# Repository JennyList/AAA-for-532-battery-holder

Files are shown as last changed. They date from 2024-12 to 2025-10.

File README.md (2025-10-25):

# AAA-for-532-battery-holder

A 3D printable battery holder designed to replace an Ever Ready 532 battery with 2 AAA cells in 1960s bellows Polaroid cameras

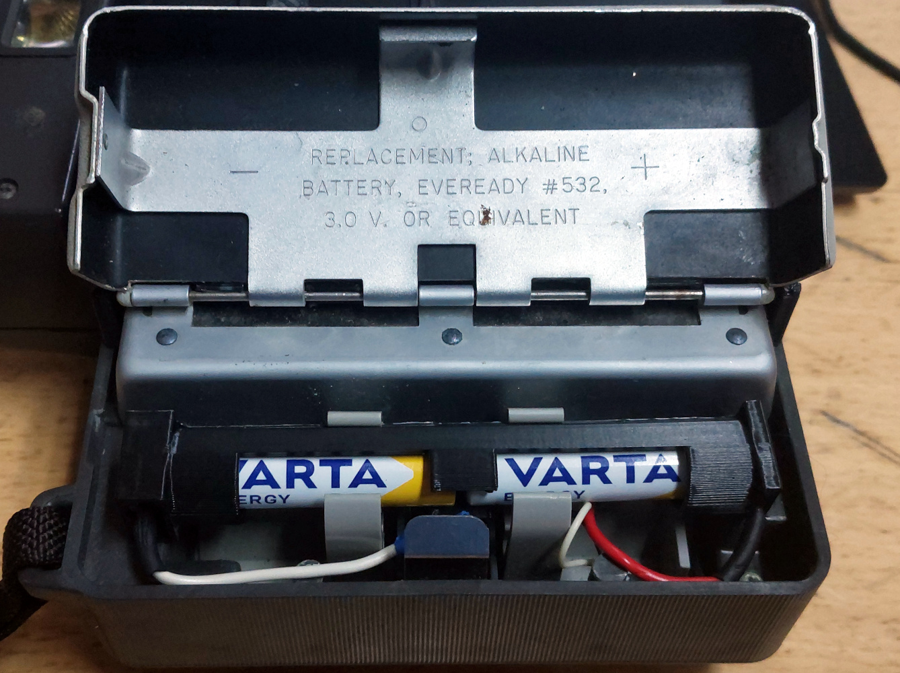
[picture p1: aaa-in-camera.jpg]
The battery holder fitted in a Polaroid 104 camera, with a pair of Varta AAA cells


## Instructions

Print the model, either from the STL file or by rendering the OpenSCAD file. I printed mine on a Prusa Mini, with a brim and with supports on the bed.

I found some spring battery terminals designed for battery boxes on AliExpress. Mine were the coiled wire type, and were designed to connect the positive of one cell to the negative of the next. I cut one into two terminals and soldered the two to a pair of wires, as shown in the image below. The spring terminals should slide into the 3D printed receptacle, the wider one being for the negative spring. You may find a set of tweezers useful here. The clip style connectors in the camera were removed, and the wires from the battery holder soldered to their wires, observing polarity. I used heat shrink sleeving for insulation on all connectors.

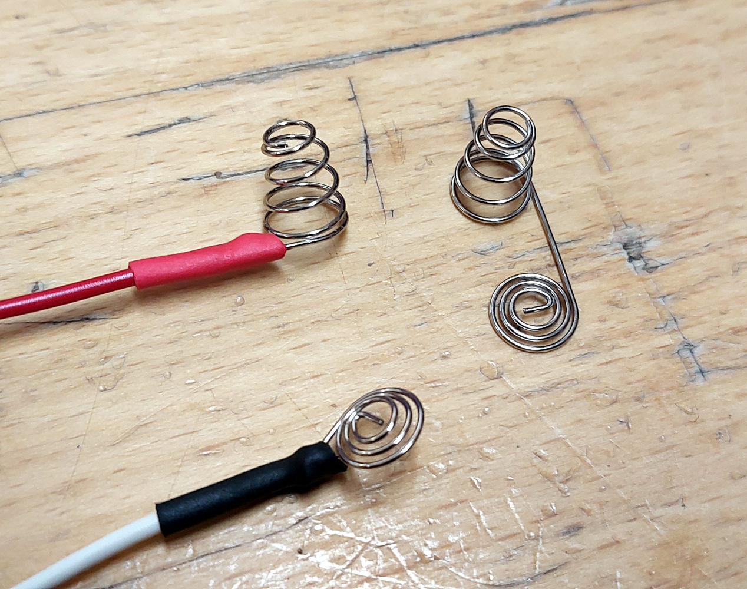
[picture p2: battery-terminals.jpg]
The battery terminals, next to one of the spring terminals I cut in half to make mine.


The resulting AAA battery holder should fit in the clip for the 532, and be short enough to fit within the battery compartment of the camera. This was tested in a Polaroid 104, and it should also work with other similar models.



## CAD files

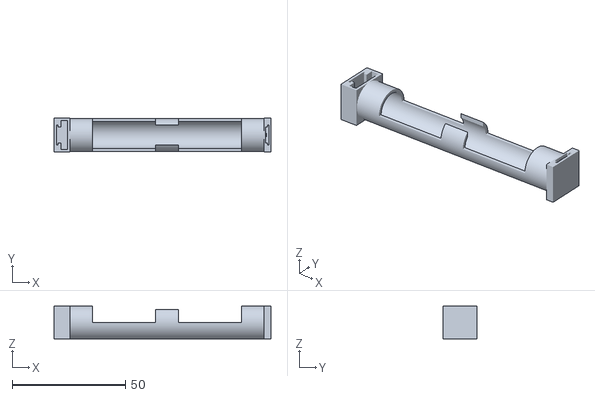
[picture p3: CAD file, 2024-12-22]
AAA-for-532-battery-holder.stl
96.0 x 15.0 x 14.5

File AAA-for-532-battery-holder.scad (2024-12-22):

/*
A 3D-printable adapter from an Ever Ready 532 to two AAA cells

(c) Jenny List 2024
CC-BY-SA 4.0

Designed for 1960s Polaroid bellows cameras which used this cell.
Tested on a Polaroid 104, other similar cameras use the same batteries.

I print this with a brim, and supports on the bed.

*/

module AAAcell(){
    cylinder(42.45,5.1,5.1);
    translate([0,0,42.45]) cylinder(1.12,1.6,1.6);
}


//translate([0,0,10]) AAAcell();
//translate([0,0,53.57]) AAAcell();
$fn=90;

rotate([0,90,0]){
    difference(){
        union(){
            translate([-7.25,-7.5,0]){
                difference(){ // -ve contact
                    cube([14.5,15,7]);
                    translate([0,1,3]) cube([13,13,3]);
                    translate([0,4,1.75]) cube([13,7,2.25]);
                    translate([0,3,1]) cube([13,9,0.75]);
                }
            }
            translate([-7.25,-7.5,93]){
                difference(){ // +ve contact
                    cube([14.5,15,3]);
                    translate([0,4,0.6]) cube([13,7,0.75]);
                    translate([0,3,1.35]) cube([13,9,0.75]);
                }
            }
            translate([0,0,7]) {
                difference(){//battery tube for 2 AAA cells
                    cylinder(86,7.25,7.25);
                    translate([-10,-4.5,10]) cube([10,9,66]);
                    translate([-10,-7.5,10]) cube([10,15,28]);
                    translate([-10,-7.5,48]) cube([10,15,28]);
                }
            }
        }
        translate([0,0,6]) cylinder(88,6,6); //middle of tube, clip to hold cells
    }
}
